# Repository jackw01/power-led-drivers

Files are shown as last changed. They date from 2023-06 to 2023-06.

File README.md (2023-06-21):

# power-led-drivers

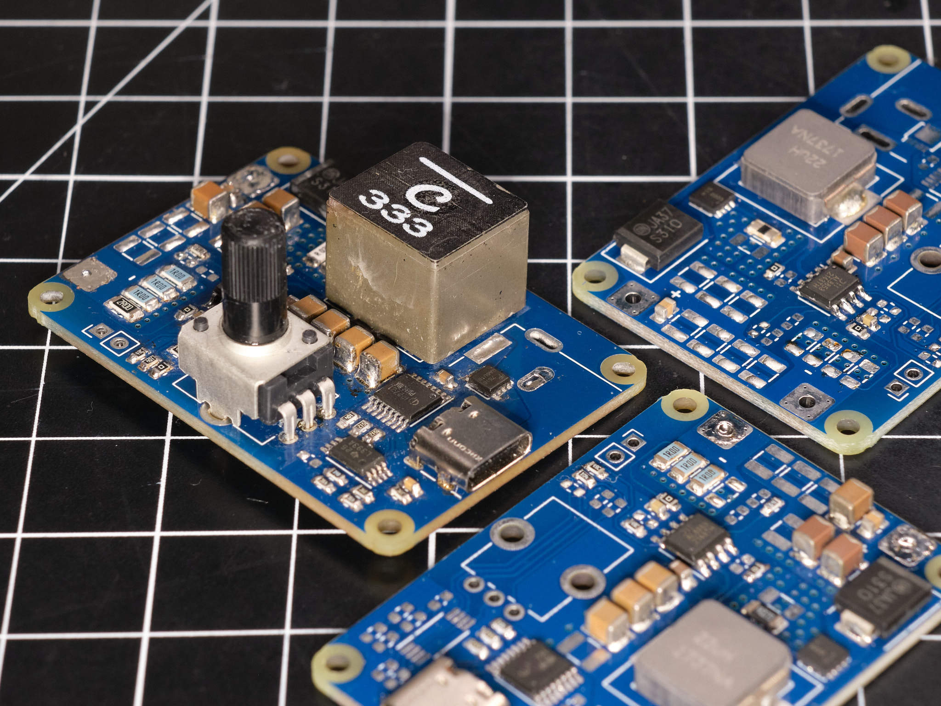
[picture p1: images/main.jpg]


## Features

### boostdriver-AL8853 rev1

* Input voltage range: 6-40V
* Input current up to 3A, higher current possible with cooling
* Output voltage up to 80V, higher voltage possible with modifications
* Up to 93% efficient at 20V input, ~75V 50W output
* Based on the [Diodes Incorporated AL8853 boost controller](https://www.diodes.com/assets/Datasheets/AL8853.pdf)
* Optional onboard USB-C power input (>50W output from USB without a heatsink)
* PWM input for brightness control
* Optional onboard dimmer for self-contained standalone use

## Design

### boostdriver-AL8853 rev1

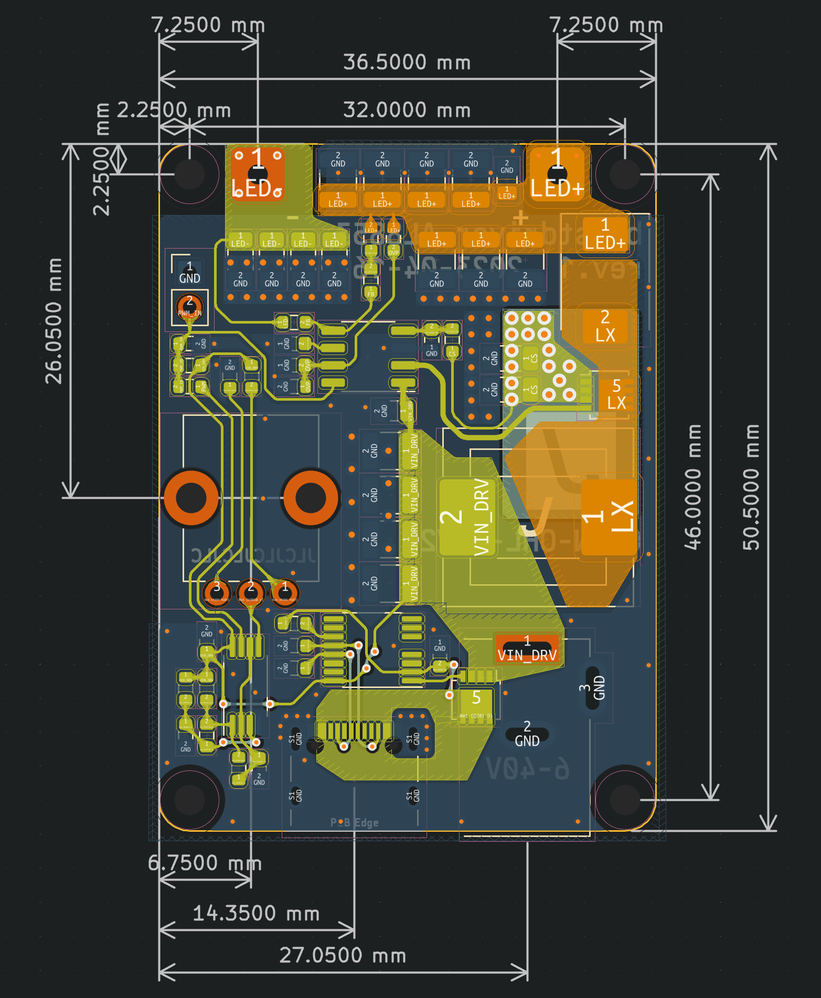
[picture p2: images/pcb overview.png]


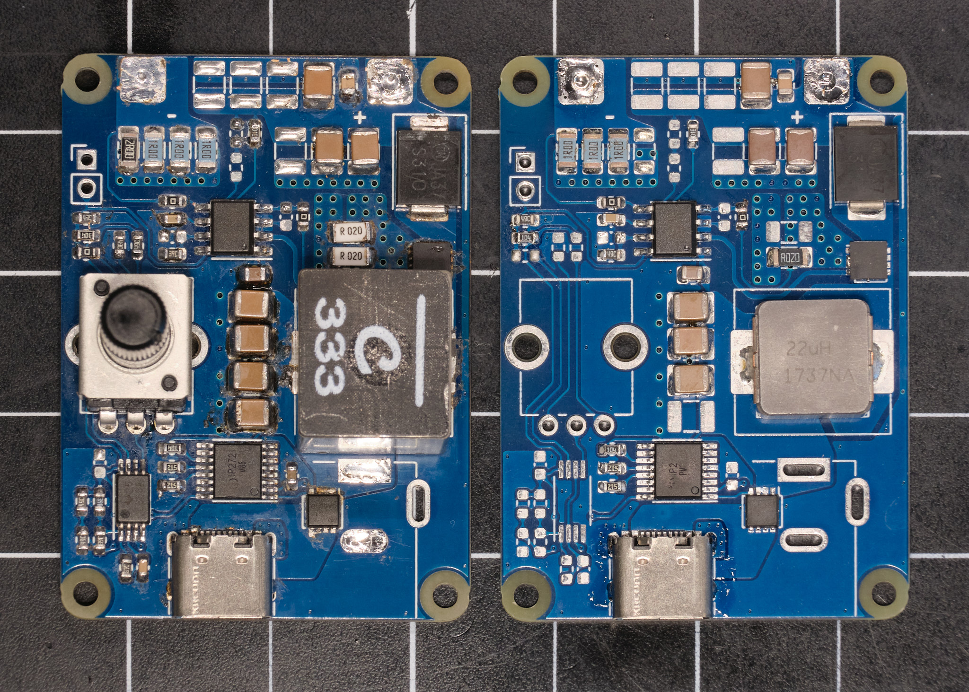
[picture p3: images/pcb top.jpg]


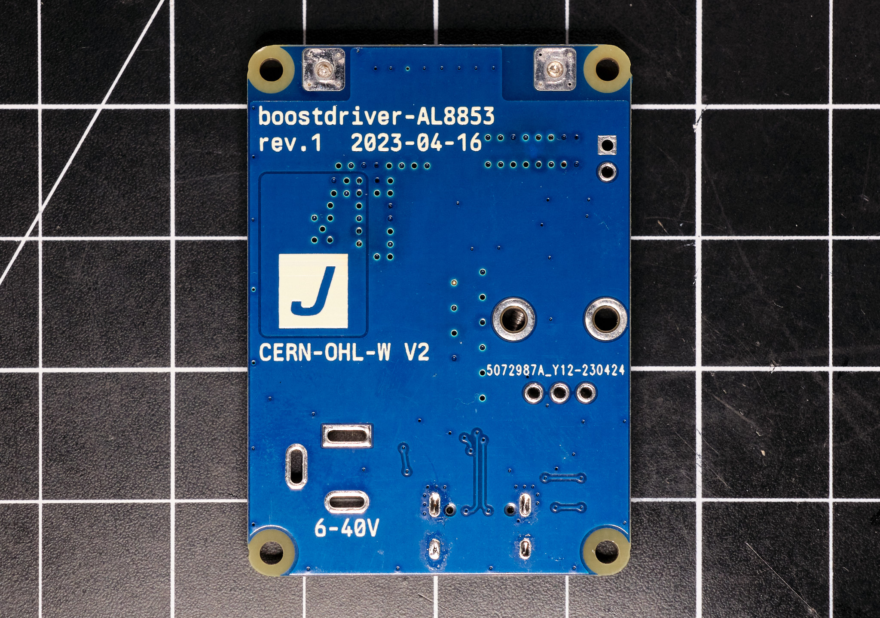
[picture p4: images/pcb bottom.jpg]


[Schematic as PDF](pcb/schematic%20rev1%2020230619-01.pdf)

## Component Selection

Component selections should be based on the <a href="https://www.diodes.com/assets/Calculators/AL8853-Calculator.xlsx">AL8853 Design Calculator spreadsheet</a> provided by Diodes Incorporated.

For most applications, the components shown in the schematic can be left as-is except for the inductor and current sense resistor. Molded composite inductors are strongly recommended, and physically larger inductors will generally provide better efficiency and thermal performance. The switching FET listed in the schematic may be out of stock, but many suitable parts are available. The PCB footprint will accommodate a 3.3mm DFN package; [this DigiKey search](https://www.digikey.com/en/products/filter/transistors-fets-mosfets-single/278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) shows compatible parts.

More detailed information on component selection is provided in the annotations in the schematic.

### License
This project is released under the CERN Open Hardware Licence Version 2 - Weakly Reciprocal (CERN-OHL-W V2).

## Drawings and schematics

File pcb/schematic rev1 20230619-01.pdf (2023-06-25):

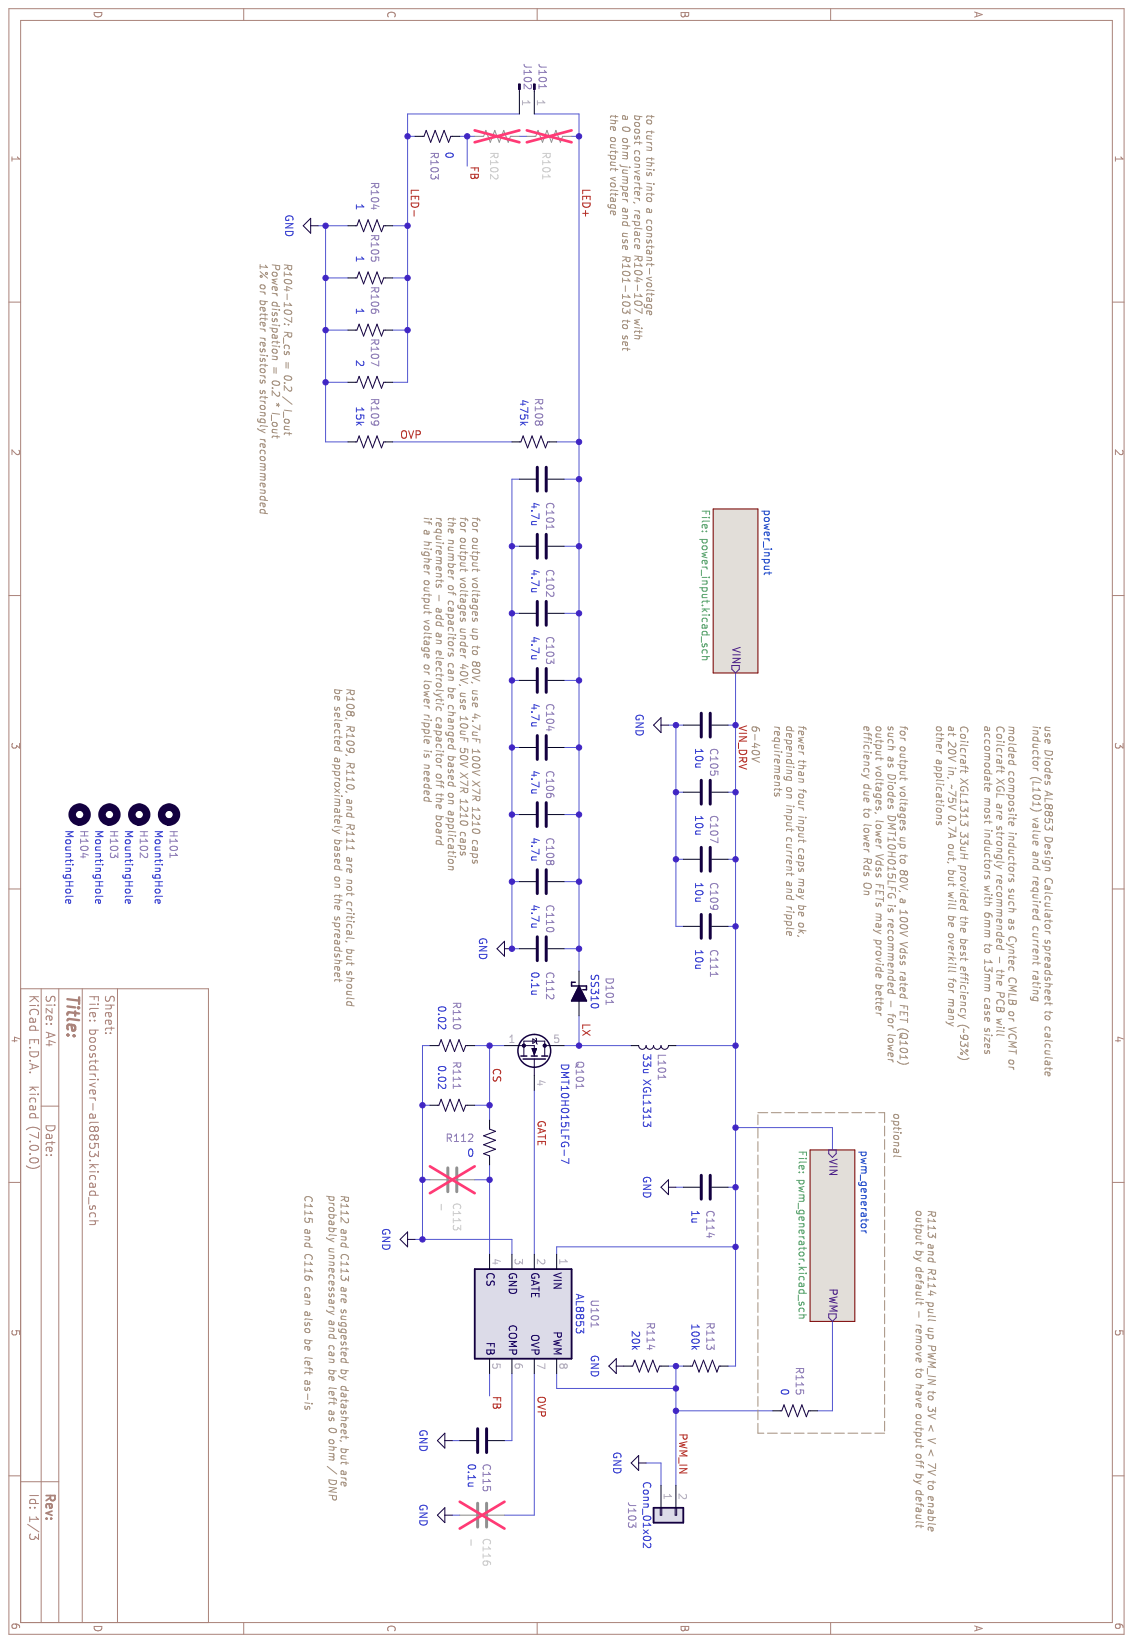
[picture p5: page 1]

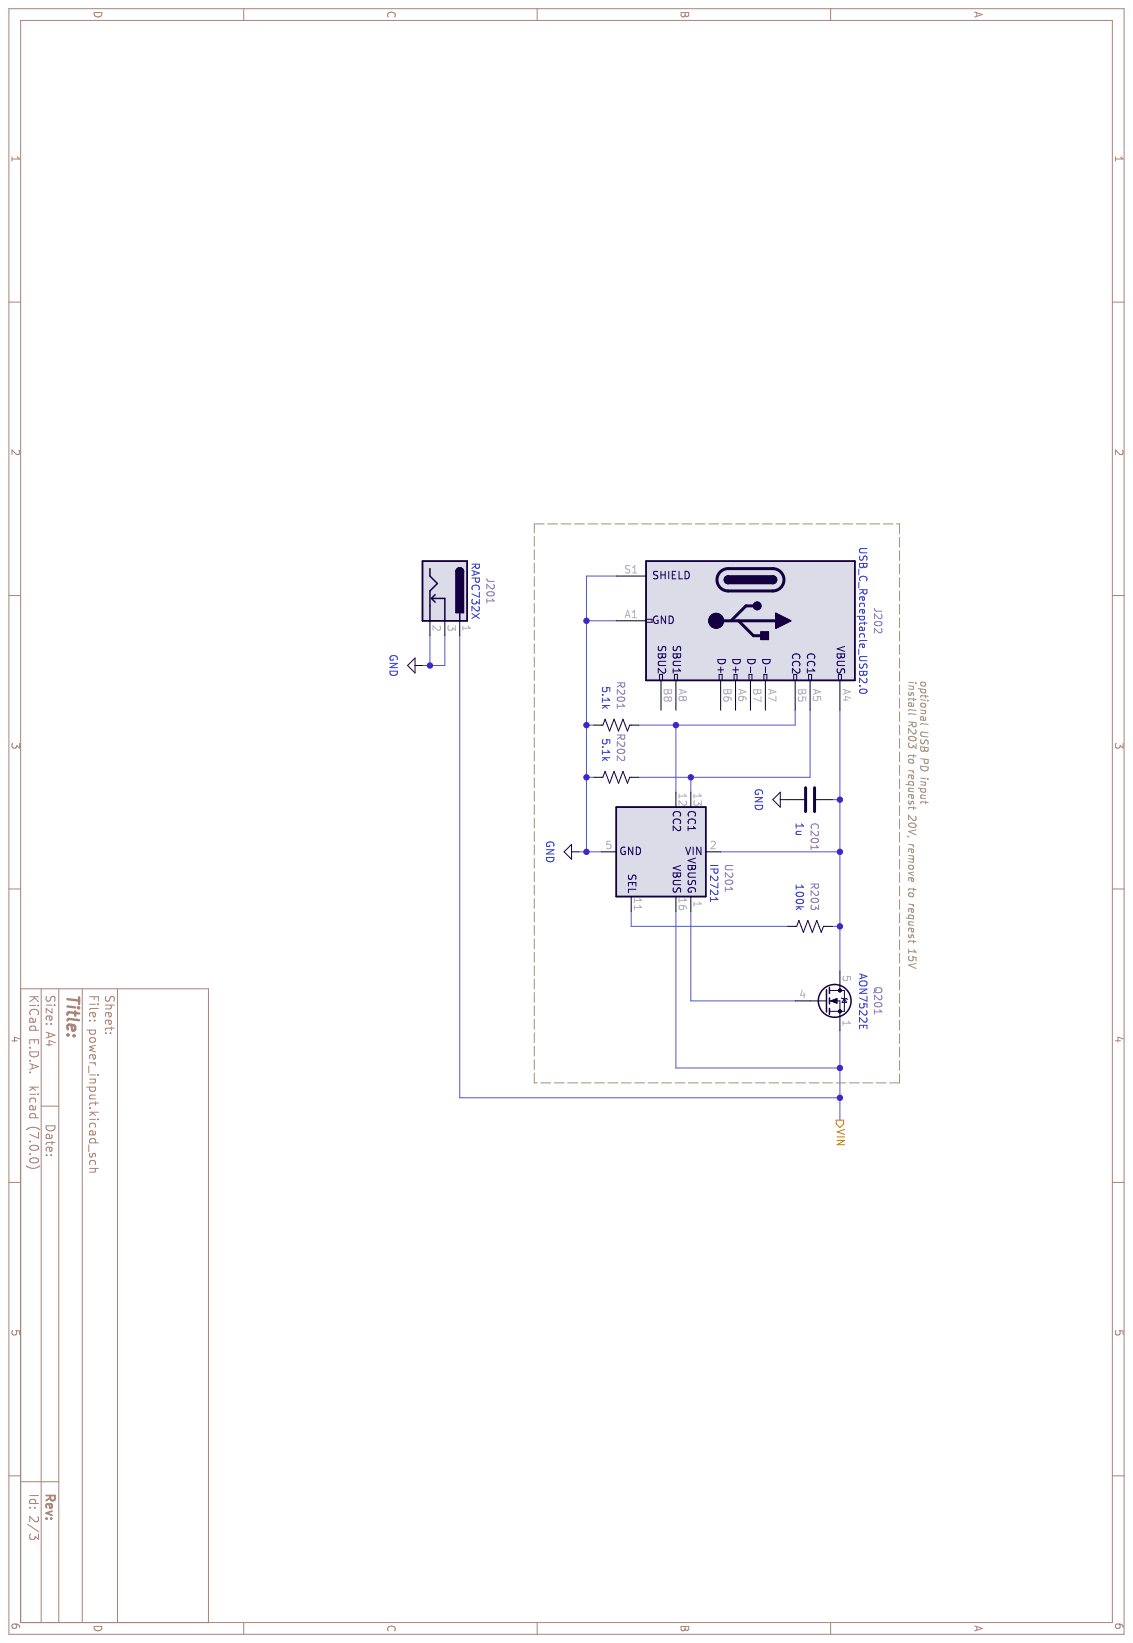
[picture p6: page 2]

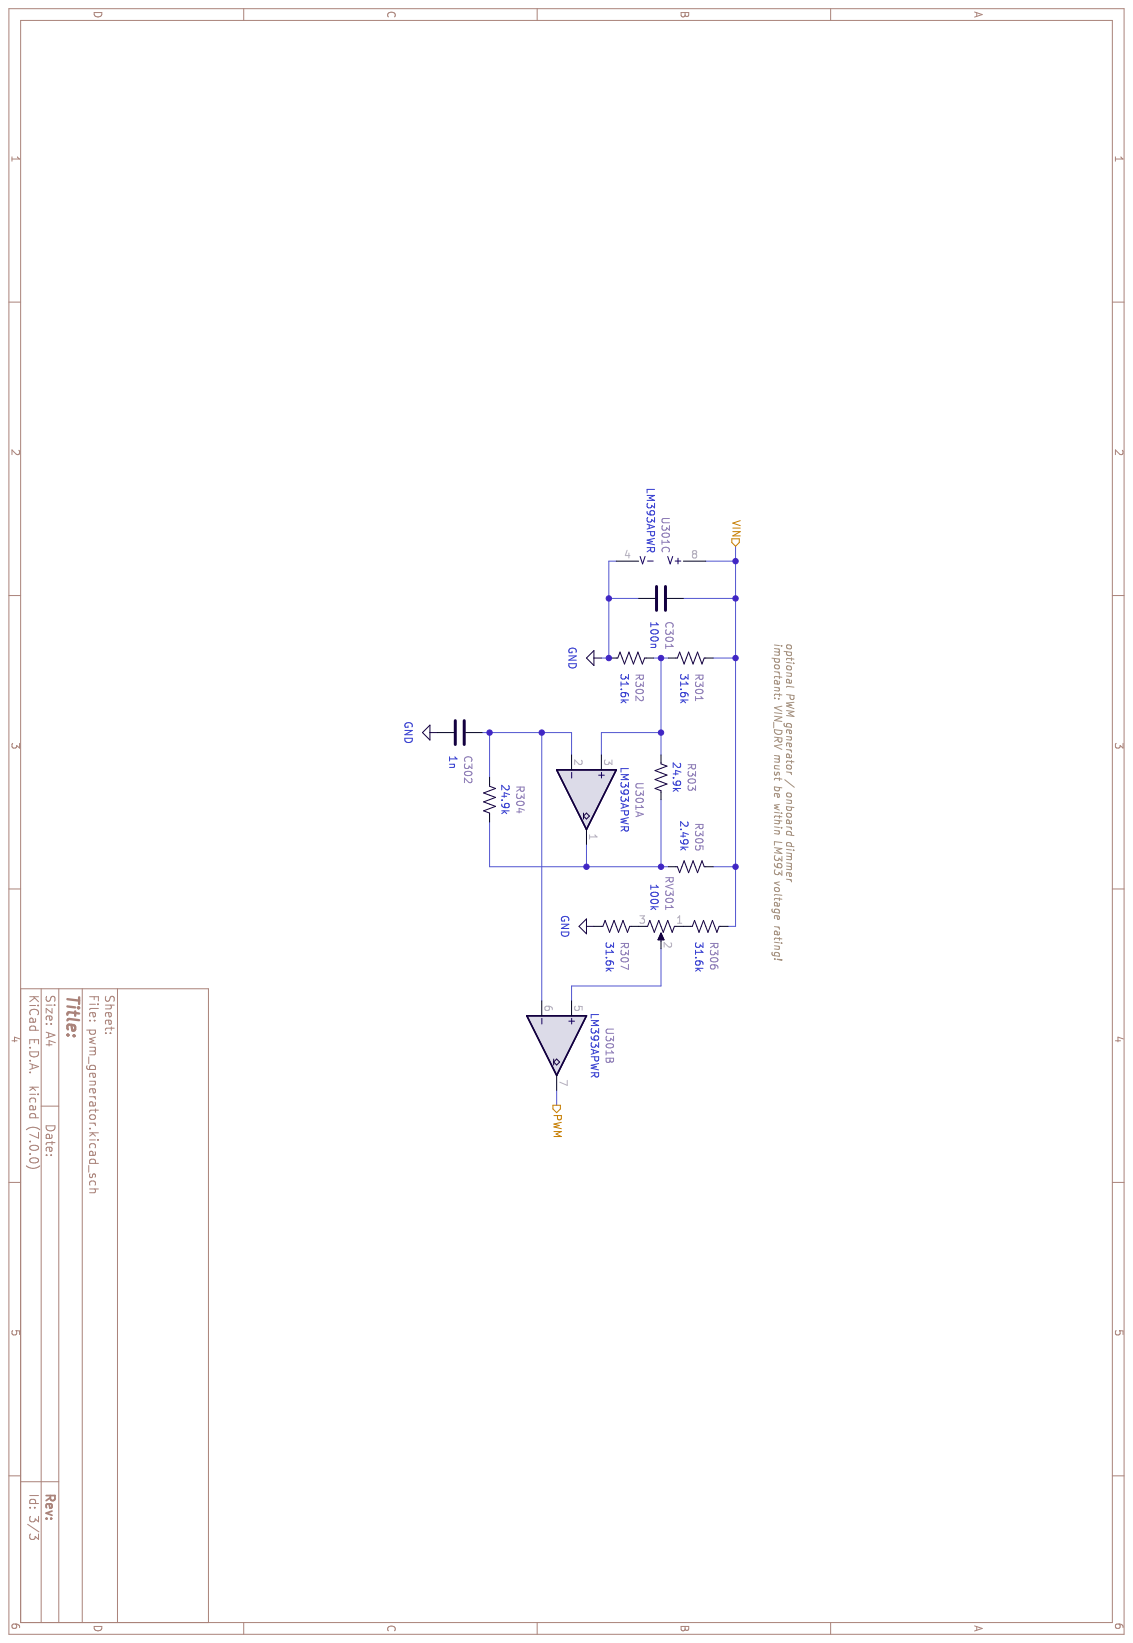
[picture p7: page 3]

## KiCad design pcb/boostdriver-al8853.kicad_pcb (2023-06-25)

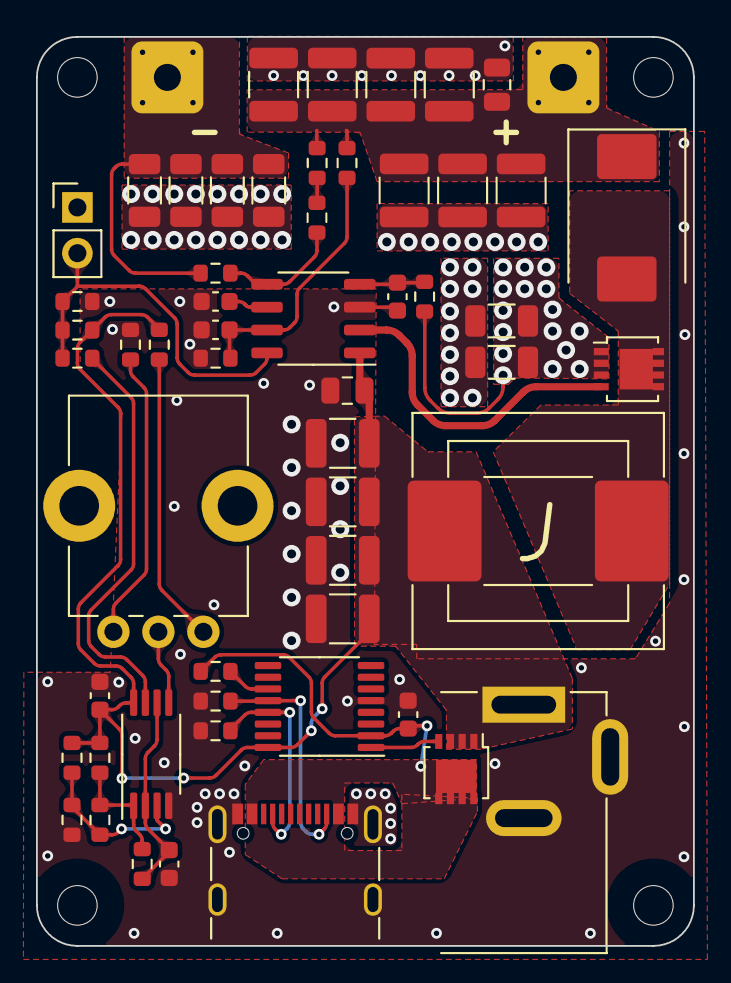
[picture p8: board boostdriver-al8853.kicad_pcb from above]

Board: 2 copper layers, 36.5 x 50.5 mm, 61 parts (0 on the bottom side), 25 nets.

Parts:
C101, C102, C103, C104, C106, C108, C110: 4.7u; C_1210_3225Metric
C105, C107, C109, C111: 10u; C_1210_3225Metric
C112: 0.1u; C_0805_2012Metric
C113, C116: -; C_0603_1608Metric
C114: 1u; C_0805_2012Metric
C115: 0.1u; C_0603_1608Metric
C201: 1u; C_0603_1608Metric
C301: 100n; C_0603_1608Metric
C302: 1n; C_0603_1608Metric
D101: SS310; D_SMC
H101, H102, H103, H104: MountingHole; MountingHole_2.2mm_M2_Mask
J101, J102: Conn_01x01_Pin; SolderWire-4x4
J103: Conn_01x02; PinHeader_1x02_P2.54mm_Vertical
J201: RAPC732X; BarrelJack_GCT_DCJ200-10-A_Horizontal
J202: USB_C_Receptacle_USB2.0; USB_C_Receptacle_GCT_USB4105-xx-A_16P_TopMnt_Horizontal
L101: 22u; L_12mm_multi
Q101, Q201: DMT10H015LFG-7; LFPAK33
R101, R102, R103, R112, R115: 0; R_0603_1608Metric
R104, R105, R106, R107: 0.3; R_1206_3216Metric
R108: 475k; R_0603_1608Metric
R109, R114: 15k; R_0603_1608Metric
R110: -; R_1206_3216Metric
R111: 0.02; R_1206_3216Metric
R113, R203: 100k; R_0603_1608Metric
R201, R202: 5.1k; R_0603_1608Metric
R301, R302, R306, R307: 31.6k; R_0603_1608Metric
R303, R304: 24.9k; R_0603_1608Metric
R305: 2.49k; R_0603_1608Metric
RV301: 100k; Potentiometer_Bourns_PTV09A-1_Single_Vertical
U101: AL8853; SO-8_3.9x4.9mm_P1.27mm
U201: IP2721; TSSOP-16_4.4x5mm_P0.65mm
U301: LM393APWR; TSSOP-8_4.4x3mm_P0.65mm

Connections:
/CS: Q101.1 (S), Q101.2 (S), Q101.3 (S), R110.1, R111.1, R112.1
/FB: R102.1, R103.2, U101.5 (FB)
/GATE: Q101.4 (G), U101.2 (GATE)
/LED+: C101.1, C102.1, C103.1, C104.1, C106.1, C108.1, C110.1, C112.1, D101.1 (K), J101.1, R101.2, R108.1
/LED-: J102.1, R103.1, R104.1, R105.1, R106.1, R107.1
/LX: D101.2 (A), L101.1, Q101.5 (D)
/OVP: C116.2, R108.2, R109.1, U101.7 (OVP)
/PWM_IN: J103.2, R113.2, R114.1, R115.2, U101.8 (PWM)
/VIN_DRV: C105.1, C107.1, C109.1, C111.1, C114.1, C301.1, J201.1, L101.2, Q201.1 (S), Q201.2 (S), Q201.3 (S), R113.1, R301.1, R305.1, R306.1, U101.1 (VIN), U201.16 (VBUS), U301.8 (V+)
/pwm_generator/PWM: R115.1, U301.7
GND: C101.2, C102.2, C103.2, C104.2, C105.2, C106.2, C107.2, C108.2, C109.2, C110.2, C111.2, C112.2, C113.1, C114.2, C115.1, C116.1, C201.1, C301.2, C302.2, J103.1, J201.2, J201.3, J202.A1 (GND), J202.A12 (GND), J202.B1 (GND), J202.B12 (GND), J202.S1 (SHIELD), R104.2, R105.2, R106.2, R107.2, R109.2, R110.2, R111.2, R114.2, R201.2, R202.2, R302.2, R307.2, U101.3 (GND), U201.5 (GND), U301.4 (V-)
unnamed: J202.A5 (CC1), R202.1, U201.13 (CC1)
unnamed: J202.B5 (CC2), R201.1, U201.12 (CC2)
unnamed: C201.2, J202.A4 (VBUS), J202.A9 (VBUS), J202.B4 (VBUS), J202.B9 (VBUS), Q201.5 (D), R203.1, U201.2 (VIN)
unnamed: Q201.4 (G), U201.1 (VBUSG)
unnamed: R101.1, R102.2
unnamed: R303.2, R304.2, R305.2, U301.1
unnamed: R306.2, RV301.1
unnamed: R307.1, RV301.3
unnamed: C115.2, U101.6 (COMP)
unnamed: C113.2, R112.2, U101.4 (CS)
unnamed: R203.2, U201.11 (SEL)
unnamed: R301.2, R302.1, R303.1, U301.3 (+)
unnamed: C302.1, R304.1, U301.2 (-), U301.6 (-)
unnamed: RV301.2, U301.5 (+)

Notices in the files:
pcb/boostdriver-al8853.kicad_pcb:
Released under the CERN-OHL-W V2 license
